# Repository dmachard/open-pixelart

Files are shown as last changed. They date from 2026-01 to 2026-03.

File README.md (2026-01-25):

# PixelBox



A Bluetooth-controlled PixelArt display (16x16 pixels) powered by **ESP32** and **WS2812B** LED matrix.

**Key Features:**
- 🎨 **Draw pixel art** instantly
- 🖼️ **Gallery Mode**: Slideshow of your saved arts
- 🕒 **Clock Mode**: Accurate time display with animations
- 💬 **Text Mode**: Scrolling text messages
- 🎮 **Games**: Tetris, Snake, Simon
- 🎵 **Audio Mode**: Visualizer for music

## Demo

<p>
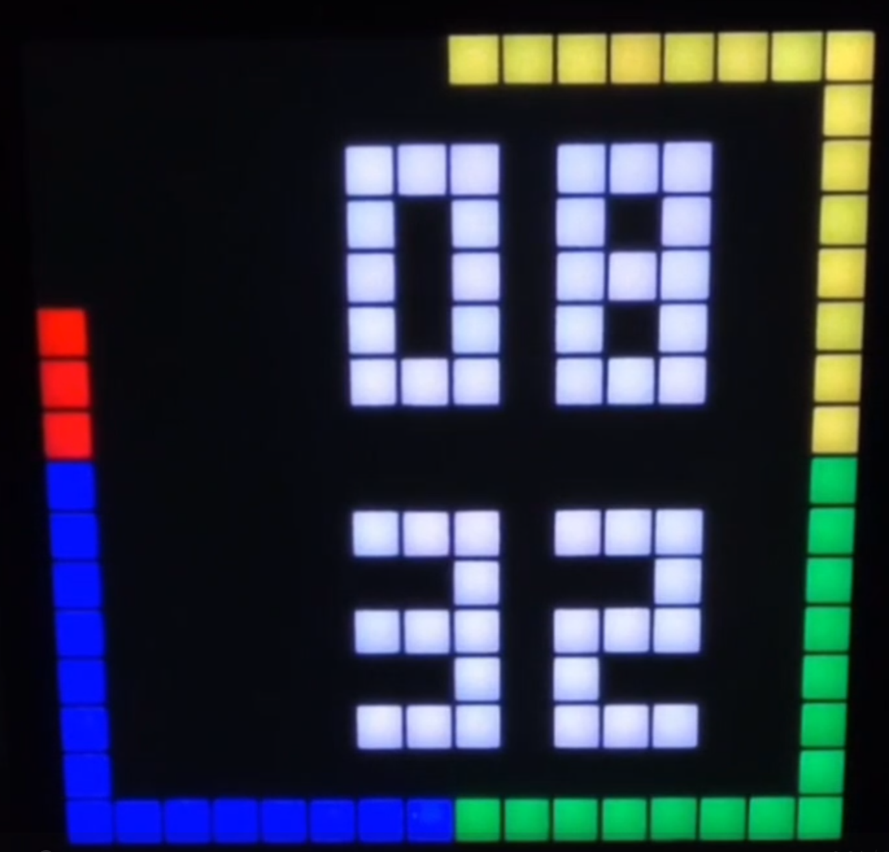
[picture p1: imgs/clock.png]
  
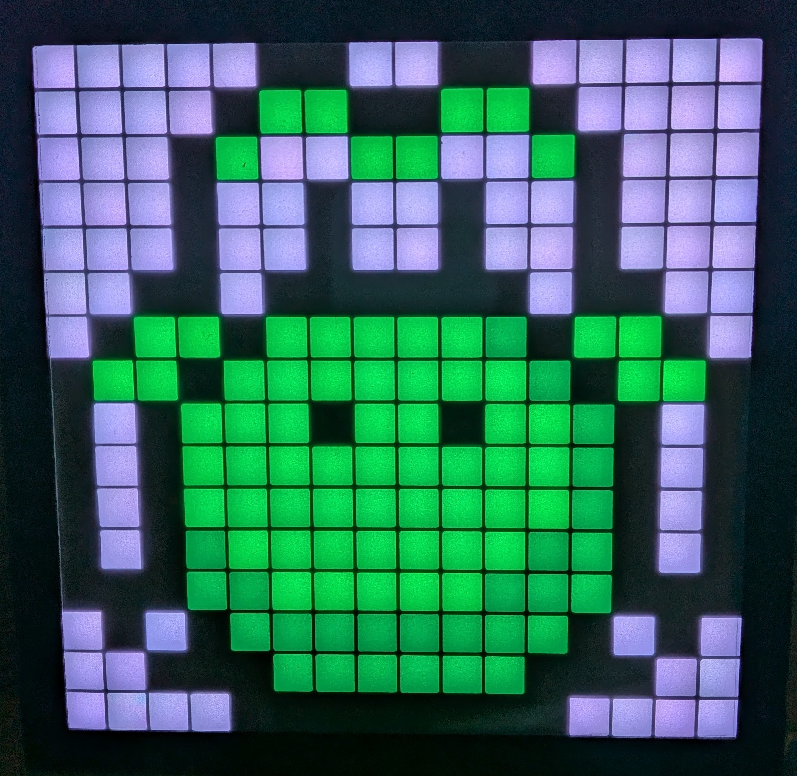
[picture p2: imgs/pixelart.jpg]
  
</p>

▶️ [See video for pixel art mode](https://github.com/user-attachments/assets/2e15cbd4-02e6-4e55-9743-37864992b4ba)

▶️ [See video for clock mode](https://github.com/user-attachments/assets/048136df-9e7c-436d-b4ce-061c26e4e01e)

## Documentation

- [🔌 Hardware Setup](docs/hardware.md): Wiring diagram and component list.
- [📱 Web Control App](docs/webapp.md): User guide for the web interface.
- [📖 Development Setup](docs/development.md): How to build and flash the firmware.
- [📡 BLE Protocol](docs/protocol.md): Details on the frame format for each mode.

- [🎨 Gallery](docs/gallery.md): Examples of pixel art and sprites.

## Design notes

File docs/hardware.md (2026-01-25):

# Hardware Setup

- **ESP32-C3 Super mini**:  Microcontroller
- **WS2812B LED Matrix 16×16**: 256 addressable RGB LEDs
- **DS3231 RTC Module**: High-precision real-time clock sensor
- **Power Supply**:  5 V DC, ≥ 1 A recommended
- **3D Printed Enclosure**: STL and FreeCAD files included in `/enclosure/`

## Wiring

| Signal | ESP32-C3 Pin | Notes |
|---|---|---|
| LED Data | GPIO 8 | Configurable via `LED_DATA_PIN` |
| RTC SDA | GPIO 6 | I2C Data line for DS3231 |
| RTC SCL | GPIO 7 | I2C Clock line for DS3231 |
| 5V | VIN | Power input |
| GND | GND | Common ground |

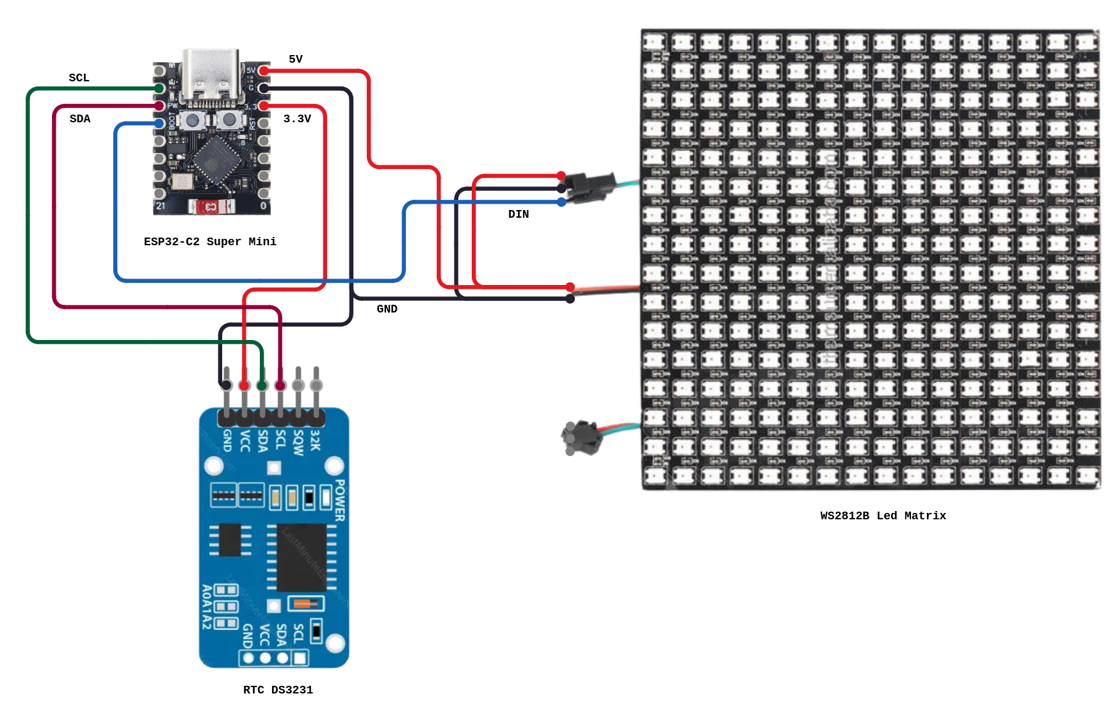
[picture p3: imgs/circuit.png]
Wiring Diagram


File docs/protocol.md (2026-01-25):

# BLE Frame Format

**Advertised Bluetooth device name:** `PixelBox`

The device receives data via the `CHAR_DATA_UUID` characteristic.
The protocol supports fragmented frames for large payloads (marker `0xFF`).

## Standard Header (8 bytes)

Used by Drawing, Gallery, Settings, Clock.

| Byte | Name | Description |
|---|---|---|
| `0` | **Mode** | `0`=Draw, `1`=Gallery, `2`=Settings, `3`=Clock |
| `1` | **Brightness** | Global brightness (0-255) |
| `2` | **Palette Size** | Number of colors following the header (max 16) |
| `3` | **Frame Index** | Current frame index or Parameter |
| `4` | **Total Frames** | Total number of frames in sequence |
| `5` | **Reserved** | Reserved for future use |
| `6-7` | **Duration** | Frame duration in seconds (uint16 little-endian) |

**Payload:**
1. **Palette**: `Palette Size * 3` bytes (R, G, B for each color).
2. **Pixels**: `128` bytes (16x16 pixels, 4 bits per pixel, packed 2 pixels per byte).

**Mode Specifics:**
*   **Settings (Mode 2)**: `Frame Index` sets the default boot mode.
*   **Clock (Mode 3)**: `Frame Index` sets the clock digit color index.

## Audio Mode (Mode 4)

| Byte | Name | Description |
|---|---|---|
| `0` | **Mode** | `4` (Audio) |
| `1` | **Brightness** | Global brightness |
| `2` | **Style** | Audio Visualizer Style ID |
| `3-7`| **Reserved** | Header padding |
| `8-23`| **Spectrum** | 16 bytes of audio spectrum data |

## Game Mode (Mode 5)

| Byte | Name | Description |
|---|---|---|
| `0` | **Mode** | `5` (Game) |
| `1-7`| **Reserved** | Header padding |
| `8-135`| **Game Data** | 128 bytes of raw pixel data (packed) |

## Text Mode (Mode 6)

**Note:** Text mode uses a custom compact format.

| Byte | Name | Description |
|---|---|---|
| `0` | **Mode** | `6` (Text) |
| `1` | **Brightness** | Global brightness |
| `2-4`| **Color** | R, G, B color for the text |
| `5` | **Speed** | Scroll speed |
| `6...`| **Message** | ASCII text string (max 128 chars) |

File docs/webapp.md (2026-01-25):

# Web Control App

The Webapp uses the Web Bluetooth API to send data directly to your ESP32-C3.
Available at https://dmachard.github.io/open-pixelart/

⚠️ Note: The Web Control App works on **Android (Chrome)** and **desktop platforms (Windows, Linux) using Chrome**. 
Other browsers may not be supported.


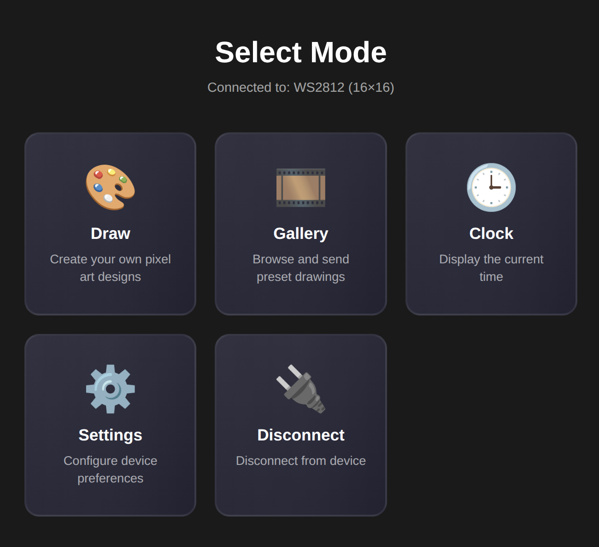
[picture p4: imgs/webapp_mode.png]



## Features

This web interface lets you:
- **Hardware Persistence**: All settings (brightness, default mode at startup, clock color) and the last displayed image are saved in the ESP32's NVS memory and restored automatically at boot.
- **Clock Mode**: Display current time with an animated edge-border seconds indicator and customizable digit colors (Lime, White, Cyan, Orange).
- Save/load drawings as `.json` files  
- Play animated slideshows

## Custom Drawings

Each drawing must be stored as a `.json` file in the `/drawings/` directory.  
Corresponding thumbnail images should be placed in the `/images/` directory.

You can generate a PNG thumbnail from any exported JSON drawing with the provided script:

```bash
cd web/
python3 -m venv venv
source venv/bin/activate
python -m pip install -r requirements.txt
python scripts/json_to_png.py drawings/led-matrix.json
```

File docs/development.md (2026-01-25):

# Development Setup

To build and flash the firmware locally, you need [PlatformIO Core](https://docs.platformio.org/en/latest/core/index.html).

## 1. Install PlatformIO
```bash
pip install -U platformio
```

## 2. Available Commands
A `Makefile` is provided for convenience:

*   **Build the firmware**:
    ```bash
    make build
    ```
*   **Flash the device**:
    (Ensure your ESP32 is connected via USB)
    ```bash
    make flash
    ```
*   **Clean build artifacts**:
    ```bash
    make clean
    ```
*   **Monitor serial output**:
    ```bash
    make monitor
    ```

## 3. Web App Development

The web application is located in the `web/` directory.

### Structure
- `web/pages/`: Contains HTML components for each screen.
- `web/index_template.html`: Main template.
- `web/index.html`: **Generated file** (do not edit manually).

### Commands

*   **Build the web app**:
    Reassembles `index.html` from components.
    ```bash
    make build-web
    ```

*   **Run locally (Docker)**:
    Starts a local Nginx server at [http://localhost:8080](http://localhost:8080).
    ```bash
    make run-web
    ```

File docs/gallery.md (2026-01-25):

# Gallery

<table>

<tr>
<td>alien</td>
<td>bear</td>
<td>bird</td>
<td>bot</td>
<td>buzz</td>
<td>cat</td>
<td>cat</td>
<td>cat</td>
</tr>

<tr>
<td>chicken</td>
<td>city</td>
<td>face</td>
<td>face</td>
<td>face</td>
<td>fox</td>
<td>fox</td>
<td>bear</td>
</tr>

<tr>
<td>frog</td>
<td>ghost</td>
<td>ghost</td>
<td>hand</td>
<td>heart</td>
<td>hellokitty</td>
<td>home</td>
<td>iloveyou</td>
</tr>

<tr>
<td>mario</td>
<td>minion</td>
<td>pacman</td>
<td>pinkflamingo</td>
<td>pockemon</td>
<td>pumpkin</td>
<td>question</td>
<td>skull</td>
</tr>

<tr>
<td>smiley</td>
<td>smiley</td>
<td>smiley</td>
<td>smiley</td>
<td>sonic</td>
<td>yoshi</td>
<td>smiley</td>
<td>candle</td>
</tr>

<tr>
<td>cat</td>
<td>cloud</td>
<td>dog</td>
<td>franchektein</td>
<td>moon</td>
<td>moon</td>
<td>star</td>
<td>whale</td>
</tr>

<tr>
<td>bot</td>
<td>skull</td>
<td>counter</td>
<td>ironman</td>
<td>rocket</td>
<td>goomba</td>
<td>clock</td>
<td>apple</td>
</tr>

<tr>
<td>playstation</td>
<td>dog</td>
<td>pikachu</td>
<td>stitch</td>
<td>ironman</td>
<td>phone</td>
<td>ghost buster</td>
<td>unicorn</td>
</tr>

<tr>
<td>christmas tree</td>
<td>note</td>
<td>open</td>
<td>ironman</td>
<td>santa</td>
<td>home</td>
<td>cat</td>
</tr>
</table>

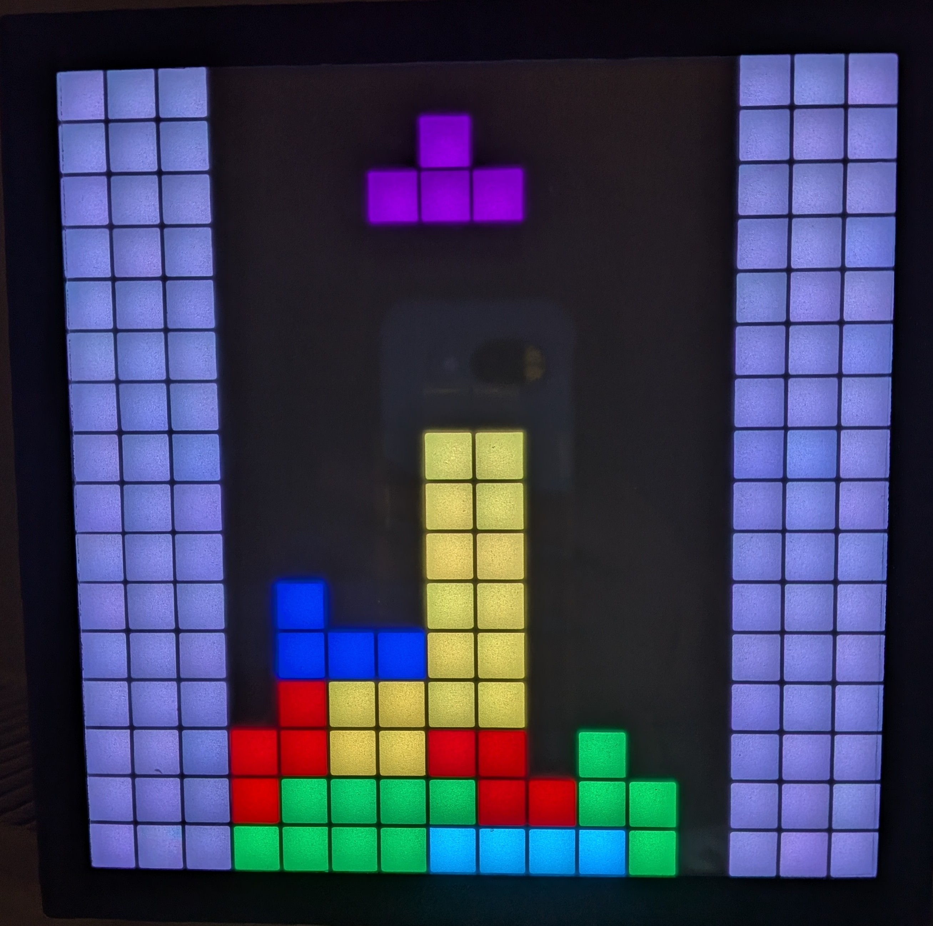
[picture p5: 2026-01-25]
imgs/tetris.jpg

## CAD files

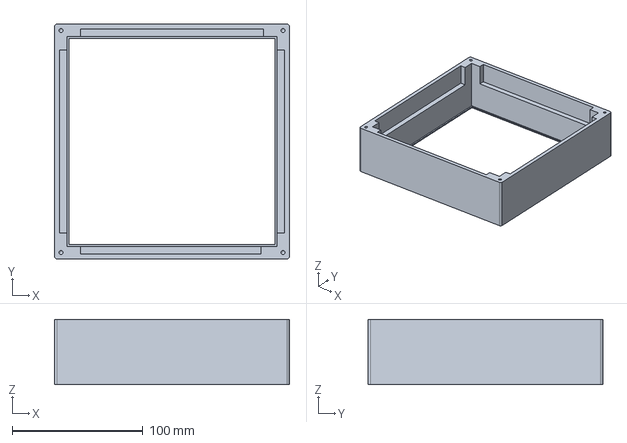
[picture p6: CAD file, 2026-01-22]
enclosure/source/front_frame.FCStd
180.0 x 180.0 x 50.0 mm

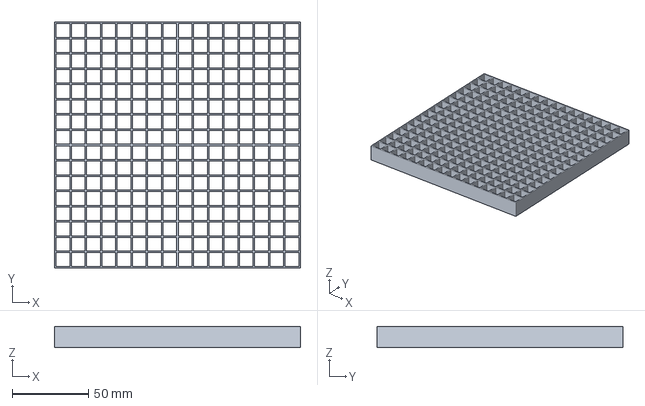
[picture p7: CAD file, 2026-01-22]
enclosure/source/matrix.FCStd
161.0 x 161.0 x 14.0 mm

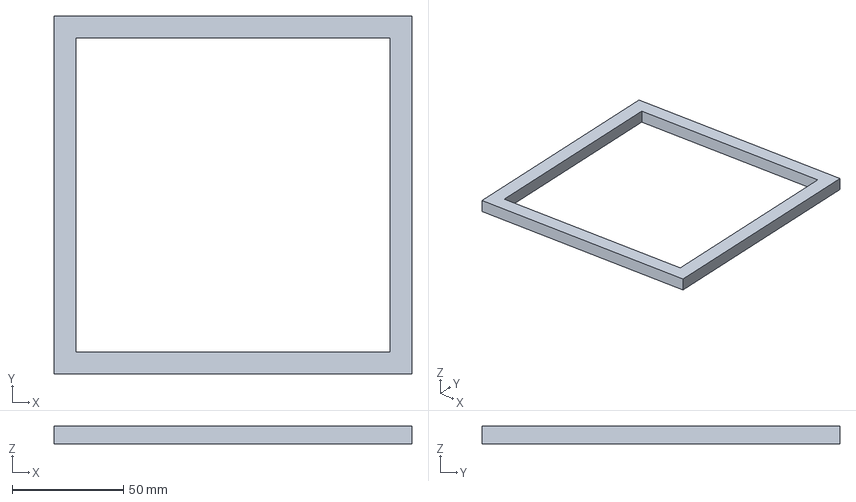
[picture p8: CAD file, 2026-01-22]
enclosure/source/led_holder.FCStd
161.0 x 161.0 x 8.00 mm

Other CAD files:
enclosure/exports/front_frame.stl
enclosure/exports/led_holder.stl
enclosure/exports/matrix.stl

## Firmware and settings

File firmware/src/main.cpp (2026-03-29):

#include <Arduino.h>

#include "ble.h"
#include "clock.h"
#include "config.h"
#include "decoder.h"
#include "display.h"
#include "nightlight.h"
#include "storage.h"
#include "text.h"

#define MAX_FRAMES 15

#include "audio.h"
#include "game.h"

FrameDecoder decoder;
Frame decodedFrame;
Frame frames[MAX_FRAMES];

uint8_t frameCount = 0;
uint8_t currentFrameIndex = 0;
unsigned long lastFrameChange = 0;

uint8_t storedBrightness = 25;
uint8_t storedClockColorIndex = 2;    // Cyan by default
uint8_t storedClockGradientIndex = 0; // Rainbow by default
uint8_t defaultMode = MODE_CLOCK;
uint8_t currentMode = MODE_CLOCK;
bool nightLightActive = false; // true while the veilleuse is displayed
bool bleActive = true;
unsigned long lastBLEActivity = 0;
uint8_t bleTimeoutMinutes = 15;

volatile bool isUpdatingDisplay = false;

void updateDisplay() {
  if (isUpdatingDisplay)
    return;
  isUpdatingDisplay = true;

  if (currentMode == MODE_TEXT) {
    updateText();
    isUpdatingDisplay = false;
    return;
  }

  if (currentMode == MODE_CLOCK) {
    updateClock();
    isUpdatingDisplay = false;
    return;
  }

  if (currentMode == MODE_GALLERY && frameCount > 0) {
    unsigned long now = millis();
    Frame &f = frames[currentFrameIndex];

    if (now - lastFrameChange >= f.duration_ms) {
      currentFrameIndex = (currentFrameIndex + 1) % frameCount;
      lastFrameChange = now;
      displayFrame(frames[currentFrameIndex]);
    }
  }
  isUpdatingDisplay = false;
}

void onIncomingData(uint8_t *data, size_t len) {
  lastBLEActivity = millis();
  if (!decoder.decode(decodedFrame, data, len)) {
    Serial.println("Failed to decode frame");
    return;
  }

  if (isUpdatingDisplay)
    return;
  isUpdatingDisplay = true;

  switch (decodedFrame.deviceMode) {
  case MODE_TEXT:
    currentMode = MODE_TEXT;
    setText(decodedFrame.textMsg, decodedFrame.textColor,
            decodedFrame.textSpeed, decodedFrame.fontIndex);

    // Update brightness if needed
    if (decodedFrame.brightness != storedBrightness) {
      storedBrightness = decodedFrame.brightness;
      setDisplayBrightness(storedBrightness);
      saveBrightness(storedBrightness);
    }
    Serial.printf("Text Mode: %s (Speed: %d)\n", decodedFrame.textMsg,
                  decodedFrame.textSpeed);
    break;

  case MODE_AUDIO:
    currentMode = MODE_AUDIO;
    setAudioStyle(decodedFrame.audioStyle);
    updateAudioSpectrum(decodedFrame.spectrum, 16);
    drawAudioVisualizer();
    break;

  case MODE_DRAW:
    currentMode = MODE_DRAW;
    frameCount = 1;
    currentFrameIndex = 0;
    frames[0] = decodedFrame;

    lastFrameChange = millis();

    if (decodedFrame.brightness != storedBrightness) {
      storedBrightness = decodedFrame.brightness;
      saveBrightness(storedBrightness);
      currentBLEBrightness = storedBrightness;
      Serial.printf("Brightness saved to NVS: %d\n", storedBrightness);
    }

    displayFrame(frames[0]);
    // REMOVED `saveFrame(frames[0]);` to prevent NVS flash wear and BLE packet
    // drops during fast drawing strokes (up to 50 frames/sec sent by webapp).
    Serial.println("Switched to DRAW Mode.");
    break;
  case MODE_GALLERY:
    currentMode = MODE_GALLERY;
    // On first frame, set total frame count
    if (decodedFrame.frameIndex == 0) {
      frameCount = min((uint8_t)decodedFrame.frameTotal, (uint8_t)MAX_FRAMES);
      currentFrameIndex = 0;
    }

    // Store the received frame at its index
    if (decodedFrame.frameIndex < frameCount) {
      frames[decodedFrame.frameIndex] = decodedFrame;
    }

    // Start slideshow if last frame received
    if (decodedFrame.frameIndex + 1 == decodedFrame.frameTotal &&
        frameCount > 0) {
      lastFrameChange = millis();

      if (decodedFrame.brightness != storedBrightness) {
        storedBrightness = decodedFrame.brightness;
        saveBrightness(storedBrightness);
        currentBLEBrightness = storedBrightness;
        Serial.printf("Brightness saved to NVS: %d\n", storedBrightness);
      }

      displayFrame(frames[0]);
      // saveFrame(frames[0]); // REMOVED: Saving during animation load causes
      // BLE drops and first frame visual glitch
      Serial.printf("Switched to GALLERY Mode: %d frames ready.\n", frameCount);
    }
    break;
  case MODE_SETTINGS:
    // Update brightness if changed
    if (decodedFrame.brightness != storedBrightness) {
      storedBrightness = decodedFrame.brightness;
      saveBrightness(storedBrightness);
      currentBLEBrightness = storedBrightness;
      Serial.printf("Brightness saved to NVS (Settings): %d\n",
                    storedBrightness);

      setDisplayBrightness(storedBrightness);

      // If there's a frame being displayed, update its brightness and refresh
      if (frameCount > 0 && currentMode != MODE_CLOCK) {
        frames[currentFrameIndex].brightness = storedBrightness;
        displayFrame(frames[currentFrameIndex]);
      } else if (currentMode == MODE_CLOCK) {
        drawClock();
        showDisplay();
      }
    }

    // Update default mode if frameIndex is used as mode carrier
    if (decodedFrame.frameIndex != 255) { // Assuming 255 means "no change"
      defaultMode = decodedFrame.frameIndex;
      saveDefaultMode(defaultMode);
      Serial.printf("Default mode saved to NVS: %d\n", defaultMode);
    }

    // Update AutoDST if frameTotal is used (0=off, 1=on, 255=no change)
    if (decodedFrame.frameTotal != 255) {
      saveAutoDST(decodedFrame.frameTotal == 1);
      Serial.printf("AutoDST saved to NVS: %d\n", decodedFrame.frameTotal == 1);
      if (currentMode == MODE_CLOCK) {
        syncClockWithRTC();
        drawClock();
        showDisplay();
      }
    }
    break;
  case MODE_CLOCK:
    currentMode = MODE_CLOCK;
    Serial.println("Switched to CLOCK Mode.");
    Serial.printf("Clock update: Idx=%d, Total=%d\n", decodedFrame.frameIndex,
                  decodedFrame.frameTotal);

    // Check if a color index was provided in frameIndex
    if (decodedFrame.frameIndex < CLOCK_PALETTE_SIZE) {
      if (storedClockColorIndex != decodedFrame.frameIndex) {
        storedClockColorIndex = decodedFrame.frameIndex;
        currentClockColorIndex = storedClockColorIndex; // Sync BLE manager
        setClockColorIndex(storedClockColorIndex);
        saveClockColor(storedClockColorIndex);
        Serial.printf("Clock color saved to NVS: %d\n", storedClockColorIndex);
      }
    }

    // Check if a gradient index was provided in frameTotal (repurposed)
    // frameTotal is typically 0 or 1 for single frame modes, but we can usage
    // it here.
    if (decodedFrame.frameTotal < 4) { // We have 4 gradients (0-3)
      if (storedClockGradientIndex != decodedFrame.frameTotal) {
        storedClockGradientIndex = decodedFrame.frameTotal;
        currentClockGradientIndex =
            storedClockGradientIndex; // Sync BLE manager
        saveClockGradient(storedClockGradientIndex);
        setClockGradientIndex(storedClockGradientIndex);
        Serial.printf("Clock gradient saved to NVS: %d\n",
                      storedClockGradientIndex);
      }
    }

    setDisplayBrightness(storedBrightness);
    syncClockWithRTC();
    drawClock();
    showDisplay();
    showDisplay();
    break;
  case MODE_GAME:
    currentMode = MODE_GAME;
    drawGameFrame(decodedFrame.gameData);
    break;
  case MODE_NIGHTLIGHT: {
    // Save and apply the new night-light configuration
    NightLightConfig cfg;
    cfg.enabled =
        (decodedFrame.textColor.r & 0x01) != 0; // mapped to textColor.r
    cfg.colorIndex = decodedFrame.frameIndex;   // mapped to frameIndex
    cfg.brightness = decodedFrame.brightness;   // mapped to brightness
    cfg.startHour = decodedFrame.frameTotal;    // mapped to frameTotal
    cfg.startMinute = decodedFrame.audioStyle;  // mapped to audioStyle
    cfg.endHour = decodedFrame.textSpeed;       // mapped to textSpeed
    cfg.endMinute = decodedFrame.fontIndex;     // mapped to fontIndex
    setNightLightConfig(cfg);
    saveNightLightConfig(cfg);
    Serial.printf("NightLight config received: enabled=%d %02d:%02d->%02d:%02d "
                  "color=%d bright=%d\n",
                  cfg.enabled, cfg.startHour, cfg.startMinute, cfg.endHour,
                  cfg.endMinute, cfg.colorIndex, cfg.brightness);
    break;
  }
  default:
    Serial.printf("Unknown Mode received: %d\n", decodedFrame.deviceMode);
    frameCount = 0;
    break;
  }
  isUpdatingDisplay = false;
}

// remove the rest of the file

void onClientDisconnect() {
  // Clear slideshow state but keep the last frame on screen
  frameCount = 0;
  currentFrameIndex = 0;
  Serial.println("Client disconnected - keeping last frame displayed");
}

void setup() {
  // 1. COMMENCE INITIALIZATION (SERIAL + STORAGE)
  Serial.begin(115200);
  Serial.println("\n--- PixelBox Stable Startup ---");

  initStorage();
  storedBrightness = loadBrightness(25);
  if (storedBrightness > 120)
    storedBrightness = 25;

  defaultMode = loadDefaultMode(MODE_CLOCK);
  currentMode = defaultMode;
  storedClockColorIndex = loadClockColor(2);
  storedClockGradientIndex = loadClockGradient(0);
  setClockColorIndex(storedClockColorIndex);
  setClockGradientIndex(storedClockGradientIndex);

  // 2. INITIALIZE DISPLAY (BLACK)
  initDisplay(storedBrightness);
  delay(200); // Let power and bus settle

  // 3. INITIALIZE RTC AND OTHER MODULES
  initClock();
  initText();
  initAudio();
  initGame();

  NightLightConfig nlCfg;
  loadNightLightConfig(nlCfg);
  setNightLightConfig(nlCfg);
  initNightLight();

  // 4. PERFORM FIRST RENDER
  syncClockWithRTC();
  if (currentMode == MODE_CLOCK) {
    drawClock();
    showDisplay();
  } else {
    if (loadFrame(frames[0])) {
      frameCount = 1;
      currentFrameIndex = 0;
      displayFrame(frames[0]);
    } else {
      currentMode = MODE_CLOCK;
      drawClock();
      showDisplay();
    }
  }

  // 5. START COMMUNICATION
  bleTimeoutMinutes = loadBLETimeout(15);
  lastBLEActivity = millis();
  initBLE(onIncomingData, onClientDisconnect, storedBrightness,
          storedClockColorIndex, storedClockGradientIndex, loadAutoDST(true));
  Serial.println("--- Setup Complete ---");
}

void loop() {
  // ---- Night-light automatic schedule check (every ~30s) ----
  static unsigned long lastNLCheck = 0;
  if (millis() - lastNLCheck >= 30000UL) {
    lastNLCheck = millis();
    syncClockWithRTC(); // refresh h/m/s from RTC
    uint8_t curH = 0, curM = 0, curS = 0;
    getCurrentTime(curH, curM, curS);
    bool shouldBeActive = isNightLightTime(curH, curM);
    if (shouldBeActive && !nightLightActive) {
      nightLightActive = true;
      Serial.println("NightLight: activating");
      drawNightLight();
    } else if (!shouldBeActive && nightLightActive) {
      nightLightActive = false;
      Serial.println("NightLight: deactivating, restoring previous mode");
      // Restore previous mode display
      if (currentMode == MODE_CLOCK) {
        setDisplayBrightness(storedBrightness);
        drawClock();
        showDisplay();
      } else if (frameCount > 0) {
        displayFrame(frames[currentFrameIndex]);
      }
    } else if (shouldBeActive && nightLightActive) {
      // Refresh the glow periodically
      drawNightLight();
    }
  }

  // Continuously update display (only when veilleuse is not active)
  if (!nightLightActive) {
    updateDisplay();
  }

  // BLE Timeout Logic
  if (bleActive) {
    if (isBLEConnected()) {
      lastBLEActivity = millis(); // Reset timeout while connected
    } else {
      if (bleTimeoutMinutes > 0 &&
          (millis() - lastBLEActivity >
           (unsigned long)bleTimeoutMinutes * 60 * 1000)) {
        Serial.println("BLE Timeout reached - stopping BLE to save power");
        stopBLE();
        bleActive = false;
      }
    }
  }

  // Allow background tasks to run
  yield();
}

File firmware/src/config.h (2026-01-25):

#ifndef CONFIG_H
#define CONFIG_H

// Select device type according to your hardware setup
#define USE_WS2812
// #define USE_HUB75

// Config BLE
#define BLE_DEVICE_NAME "PixelBox"
#define SERVICE_UUID "12345678-1234-1234-1234-123456789012"
#define CHAR_DATA_UUID "87654321-4321-4321-4321-210987654321"
#define CHAR_INFO_UUID "12345678-4321-1234-4321-123456789012"

// Device-specific configurations
#ifdef USE_WS2812
#define DEVICE_MODEL "WS2812"
#define LED_DATA_PIN 8
#define MATRIX_WIDTH 16
#define MATRIX_HEIGHT 16
#define NUM_LEDS (MATRIX_WIDTH * MATRIX_HEIGHT)
#endif

// RTC (DS3231) Configuration
#define RTC_SDA_PIN 6
#define RTC_SCL_PIN 7

#endif

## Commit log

2025-11-23 add circuit
2025-11-29 fix: update esp32.js transition handling and version in index.html
2025-11-30 feat: add frame duration selection to slideshow and update ESP32 handling
2025-12-03 feat: add device info
2025-12-06 switch ble to NimBLE-Arduino
2025-12-07 fix connect button
2025-12-24 Revise Bluetooth device name and browser support notes
    Updated Bluetooth device name and added notes about browser support.
2026-01-18 feat: Implement NVS persistence for the last displayed frame and retain it on client disconnect.
2026-01-22 update README and enclosure
    [front_frame.FCStd, front_frame.stl, led_holder.FCStd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]
2026-01-25 feat: Implement interruptible slideshow uploads, restrict firmware slideshow to gallery mode, and re-enable connect button on BLE disconnect.
2026-03-22 feat: Configure BLE advertisement to include device name and service UUID.
2026-03-25 feat: Implement configurable BLE timeout to deinitialize BLE after inactivity for power saving.
